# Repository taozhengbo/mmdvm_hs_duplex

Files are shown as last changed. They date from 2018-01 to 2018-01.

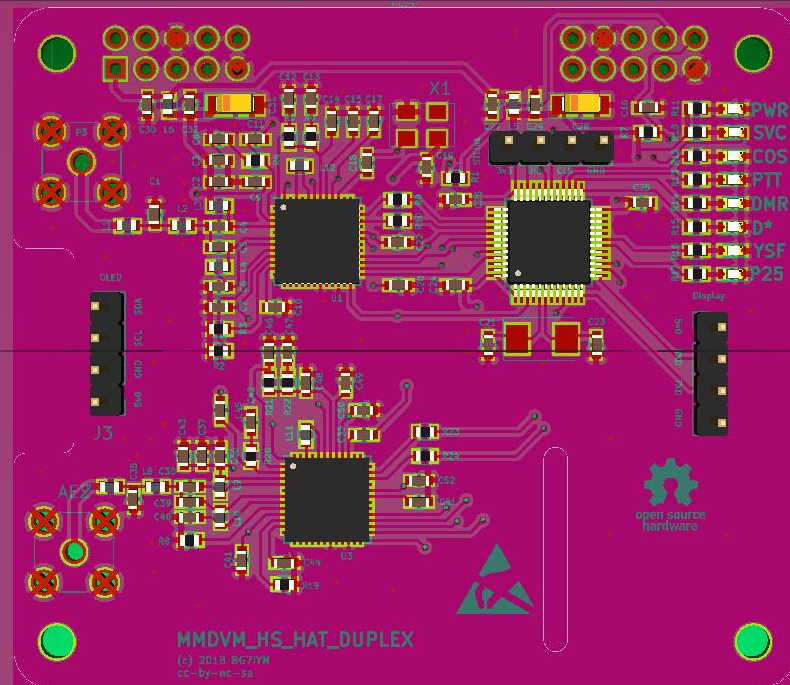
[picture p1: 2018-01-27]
mmdvm_hs-hat-duplex.png

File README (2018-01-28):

# MMDVM_HS_Hat_Duplex
MMDVM_HS Hat Duplex Ver for the Raspberry Pi 

This project provides a Raspberry Pi Hat for the [MMDVM_HS Hotspot](https://github.com/juribeparada/MMDVM_HS). It was designed for the Raspberry Pi any Version, but should work on any other Pi with the Hat interface. 

First revisions of the board have been built successfully!

The PCB is designed in KiCad and the necessary libraries are included. The supplied Gerber files can be used to order PCBs, for example at Elecrow or DirtyPCBs. 

### Revision 1.0 2018-1.25 Tested OK

Either the ADF7021 or the ADF7021-N can be used. Define the proper version in the firmware!

## Firmware Installation
For specific details about the firmware installation, check [these](https://github.com/juribeparada/MMDVM_HS#build-de-firmware-and-upload-to-zumspot-rpi) instructions.  

Enable the following settings in Config.h:

    #define MMDVM_HS_HAT_REV12
    #define ENABLE_ADF7021
    #define ADF7021_14_7456
    #define STM32_USART1_HOST
    #define ENABLE_SCAN_MODE
    #define DUPLEX
it work both DUPLEX or no DUPLEX mode,when in DUPLEX Mode Main RF is TX,Second RF is RX    
Build the firmware:

    make

And finally upload the firmware to the MMDVM_HS_Hat:

    sudo make mmdvm_hs_hat

## License
This project is released under the Creative Commons Attribution-NonCommercial-ShareAlike 3.0 (CC-BY-NC-SA 3.0, https://creativecommons.org/licenses/by-nc-sa/3.0/) license. You may edit and share it as you like, as long as credit is given and the license is not changed. You can build as many boards for you and your friends as you like and you can even sell it to them to cover your costs, **however it is strictly forbidden to turn this into a commercial product! You are not allowed to build and sell these boards for profit!**

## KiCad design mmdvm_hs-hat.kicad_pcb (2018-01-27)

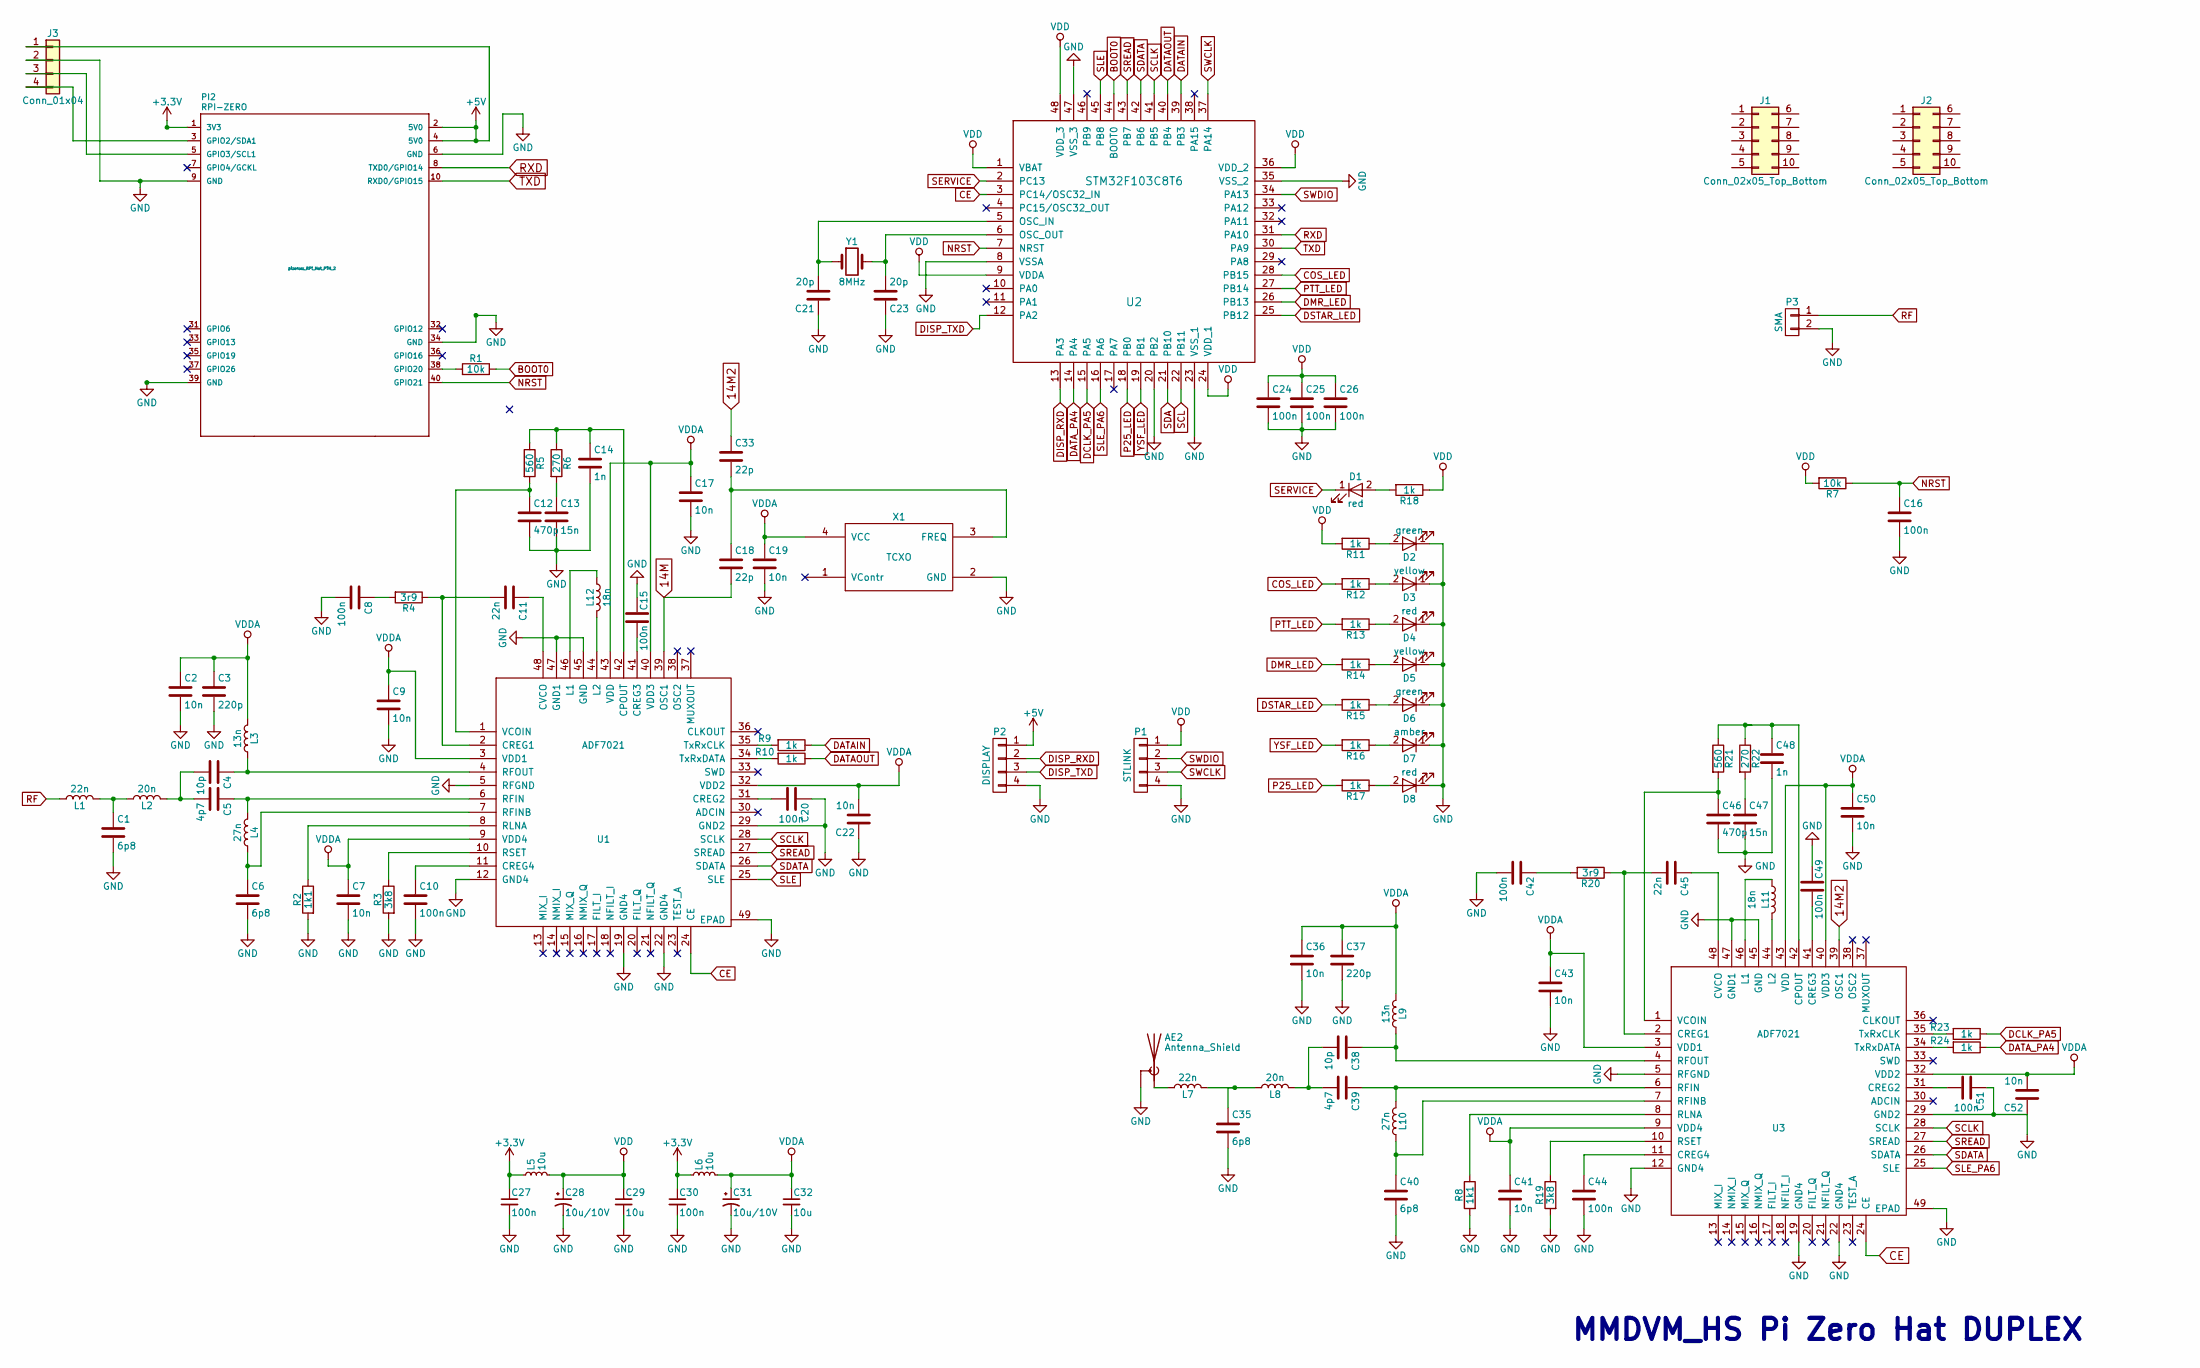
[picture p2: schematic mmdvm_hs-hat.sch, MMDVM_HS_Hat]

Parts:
AE2: Antenna_Shield; SMA_THT_Jack_Straight
C1, C6, C35, C40: 6p8; C_0603; MPN GJM1555C1H6R8BB01D
C2, C7, C9, C17, C19, C22, C36, C41, C43, C50, C52: 10n; C_0603; MPN GRM155R71H103KA88D
C3, C37: 220p; C_0603; MPN GRM1555C1H221JA01D
C4, C38: 10p; C_0603; MPN GRM0225C1C100JA03L
C5, C39: 4p7; C_0603; MPN GRM1555C1H4R7CA01D
C8, C10, C15, C16, C20, C24, C25, C26, C42, C44, C49, C51: 100n; C_0603; MPN GRM022R60J104KE15L
C11, C45: 22n; C_0603; MPN GCM155R71E223KA55D
C12, C46: 470p; C_0603; MPN GRM155R71H471KA01D
C13, C47: 15n; C_0603; MPN GRM155R71C153KA01D
C14, C48: 1n; C_0603; MPN GRM155R60J105KE19D
C18, C33: 22p; C_0603; MPN 04025A220GAT2A
C21, C23: 20p; C_0603; MPN GJM1555C1H200FB01D
C27, C30: 100n; C_0603
C28, C31: 10u/10V; CP_Tantalum_Case-A_EIA-3216-18_Reflow
C29, C32: 10u; C_0603
D1, D4, D8: red; LED_0603; MPN SML-P12U2TT86R
D2, D6: green; LED_0603; MPN SML-P13PTT86R
D3, D5: yellow; LED_0603; MPN SML-P12WTT86R
D7: amber; LED_0603; MPN SML-P12DTT86R
J1, J2: Conn_02x05_Top_Bottom; Pin_Header_Straight_2x05_Pitch2.54mm_SMD
J3: Conn_01x04; Pin_Header_Straight_1x04_Pitch2.54mm
L1, L7: 22n; L_0603; MPN 0402AF-220XJLU
L2, L8: 20n; L_0603; MPN 36501E20NJTDG
L3, L9: 13n; L_0603; MPN 0402CS-13NXJLU
L4, L10: 27n; L_0603; MPN 0402CS-27NXJLU
L5, L6: 10u; L_0603
L11, L12: 18n; L_0603; MPN 0402CS-13NXJLU
P1: STLINK; Pin_Header_Straight_1x04_Pitch2.54mm; MPN 826629-4
P2: DISPLAY; Pin_Header_Straight_1x04_Pitch2.54mm; MPN 826629-4
P3: SMA; SMA_THT_Jack_Straight; MPN 5-1814832-1
PI2: RPI-ZERO; z_RPi_Hat_PTH_2
R1, R7: 10k; R_0603; MPN CRCW040210K0FKED
R2, R8: 1k1; R_0603; MPN RR0510P-112-D
R3, R19: 3k8; R_0603; MPN RR0510P-3831-D
R4, R20: 3r9; R_0603; MPN CRCW04023R90FKED
R5, R21: 560; R_0603; MPN ERA-2AEB561X
R6, R22: 270; R_0603; MPN ERA-2AEB271X
R9, R10, R11, R12, R13, R14, R15, R16, R17, R18, R23, R24: 1k; R_0603; MPN ERJ-PA2D1001X
U1: ADF7021; QFN-48-1EP_7x7mm_Pitch0.5mm; MPN ADF7021BCPZ
U2: STM32F103C8T6; LQFP-48_7x7mm_Pitch0.5mm; MPN STM32F103C8T6
U3: ADF7021; _ADF7021_QFN-48-1EP_7x7mm_Pitch0.5mm
X1: TCXO; Oscillator_SMD_TXC_7C-4pin_5.0x3.2mm; MPN ECS-TXO-3225-147.4-TR
Y1: 8MHz; Crystal_SMD_Abracon_ABM3-2pin_5.0x3.2mm; MPN ABM3-8.000MHz-D2Y-T

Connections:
14M: C18.2, U1.39 (OSC1)
14M2: C33.1, U3.39 (OSC1)
+3V3: C27.1, C30.1, L5.1, L6.1, PI2.1 (3V3)
+5V: J3.1, P2.1, PI2.2 (5V0), PI2.4 (5V0)
BOOT0: R1.1, U2.44 (BOOT0)
CE: U1.24 (CE), U2.3 (PC14/OSC32_IN), U3.24 (CE)
COS_LED: R12.2, U2.28 (PB15)
DATAIN: R9.1, U2.39 (PB3)
DATAOUT: R10.1, U2.40 (PB4)
DATA_PA4: R24.1, U2.14 (PA4)
DCLK_PA5: R23.1, U2.15 (PA5)
DISP_RXD: P2.2, U2.13 (PA3)
DISP_TXD: P2.3, U2.12 (PA2)
DMR_LED: R14.2, U2.26 (PB13)
DSTAR_LED: R15.2, U2.25 (PB12)
GND: AE2.2 (Shield), C1.2, C2.2, C3.2, C6.2, C7.2, C8.2, C9.2, C10.2, C12.2, C13.2, C14.2, C15.1, C16.2, C17.2, C19.2, C20.1, C21.1, C22.1, C23.1, C24.2, C25.2, C26.2, C27.2, C28.2, C29.2, C30.2, C31.2, C32.2, C35.2, C36.2, C37.2, C40.2, C41.2, C42.2, C43.2, C44.2, C46.2, C47.2, C48.2, C49.1, C50.2, C51.1, C52.1, D2.1 (K), D3.1 (K), D4.1 (K), D5.1 (K), D6.1 (K), D7.1 (K), D8.1 (K), J3.2, P1.4, P2.4, P3.2, PI2.6 (GND), PI2.9 (GND), PI2.34 (GND), PI2.39 (GND), R2.2, R3.2, R8.2, R19.2, U1.5 (RFGND), U1.12 (GND4), U1.19 (GND4), U1.22 (GND4), U1.29 (GND2), U1.45 (GND), U1.47 (GND1), U1.49 (EPAD), U2.8 (VSSA), U2.20 (PB2), U2.23 (VSS_1), U2.35 (VSS_2), U2.47 (VSS_3), U3.5 (RFGND), U3.12 (GND4), U3.19 (GND4), U3.22 (GND4), U3.29 (GND2), U3.45 (GND), U3.47 (GND1), U3.49 (EPAD), X1.2 (GND)
NRST: C16.1, PI2.40 (GPIO21), R7.1, U2.7 (NRST)
unnamed: AE2.1 (A), L7.1
unnamed: C1.1, L1.2, L2.1
unnamed: C4.1, L3.1, U1.4 (RFOUT)
unnamed: C4.2, C5.2, L2.2
unnamed: C5.1, L4.2, U1.6 (RFIN)
unnamed: C6.1, L4.1, U1.7 (RFINB)
unnamed: C8.1, R4.2
unnamed: C10.1, U1.11 (CREG4)
unnamed: C11.1, U1.48 (CVCO)
unnamed: C11.2, R4.1, U1.2 (CREG1)
unnamed: C12.1, R5.2, U1.1 (VCOIN)
unnamed: C13.1, R6.2
unnamed: C14.1, R5.1, R6.1, U1.42 (CPOUT)
unnamed: C15.2, U1.41 (CREG3)
unnamed: C18.1, C33.2, X1.3 (FREQ)
unnamed: C20.2, U1.31 (CREG2)
unnamed: C21.2, U2.5 (OSC_IN), Y1.1
unnamed: C23.2, U2.6 (OSC_OUT), Y1.2
unnamed: C35.1, L7.2, L8.1
unnamed: C38.1, L9.1, U3.4 (RFOUT)
unnamed: C38.2, C39.2, L8.2
unnamed: C39.1, L10.2, U3.6 (RFIN)
unnamed: C40.1, L10.1, U3.7 (RFINB)
unnamed: C42.1, R20.2
unnamed: C44.1, U3.11 (CREG4)
unnamed: C45.1, U3.48 (CVCO)
unnamed: C45.2, R20.1, U3.2 (CREG1)
unnamed: C46.1, R21.2, U3.1 (VCOIN)
unnamed: C47.1, R22.2
unnamed: C48.1, R21.1, R22.1, U3.42 (CPOUT)
unnamed: C49.2, U3.41 (CREG3)
unnamed: C51.2, U3.31 (CREG2)
unnamed: D1.2 (A), R18.2
unnamed: D2.2 (A), R11.1
unnamed: D3.2 (A), R12.1
unnamed: D4.2 (A), R13.1
unnamed: D5.2 (A), R14.1
unnamed: D6.2 (A), R15.1
unnamed: D7.2 (A), R16.1
unnamed: D8.2 (A), R17.1
unnamed: J3.3, PI2.5 (GPIO3/SCL1)
unnamed: J3.4, PI2.3 (GPIO2/SDA1)
unnamed: L11.1, U3.46 (L1)
unnamed: L11.2, U3.44 (L2)
unnamed: L12.1, U1.46 (L1)
unnamed: L12.2, U1.44 (L2)
unnamed: PI2.38 (GPIO20), R1.2
unnamed: R2.1, U1.8 (RLNA)
unnamed: R3.1, U1.10 (RSET)
unnamed: R8.1, U3.8 (RLNA)
unnamed: R9.2, U1.35 (TxRxCLK)
unnamed: R10.2, U1.34 (TxRxDATA)
unnamed: R19.1, U3.10 (RSET)
unnamed: R23.2, U3.35 (TxRxCLK)
unnamed: R24.2, U3.34 (TxRxDATA)
P25_LED: R17.2, U2.18 (PB0)
PTT_LED: R13.2, U2.27 (PB14)
RF: L1.1, P3.1
RXD: PI2.8 (TXD0/GPIO14), U2.31 (PA10)
SCL: U2.22 (PB11)
SCLK: U1.28 (SCLK), U2.41 (PB5), U3.28 (SCLK)
SDA: U2.21 (PB10)
SDATA: U1.26 (SDATA), U2.42 (PB6), U3.26 (SDATA)
SERVICE: D1.1 (K), U2.2 (PC13)
SLE: U1.25 (SLE), U2.45 (PB8)
SLE_PA6: U2.16 (PA6), U3.25 (SLE)
SREAD: U1.27 (SREAD), U2.43 (PB7), U3.27 (SREAD)
SWCLK: P1.3, U2.37 (PA14)
SWDIO: P1.2, U2.34 (PA13)
TXD: PI2.10 (RXD0/GPIO15), U2.30 (PA9)
VDD: C24.1, C25.1, C26.1, C28.1, C29.1, L5.2, P1.1, R7.2, R11.2, R18.1, U2.1 (VBAT), U2.9 (VDDA), U2.24 (VDD_1), U2.36 (VDD_2), U2.48 (VDD_3)
VDDA: C2.1, C3.1, C7.1, C9.1, C17.1, C19.1, C22.2, C31.1, C32.1, C36.1, C37.1, C41.1, C43.1, C50.1, C52.2, L3.2, L6.2, L9.2, U1.3 (VDD1), U1.9 (VDD4), U1.32 (VDD2), U1.40 (VDD3), U1.43 (VDD), U3.3 (VDD1), U3.9 (VDD4), U3.32 (VDD2), U3.40 (VDD3), U3.43 (VDD), X1.4 (VCC)
YSF_LED: R16.2, U2.19 (PB1)

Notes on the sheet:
MMDVM_HS Pi Zero Hat DUPLEX

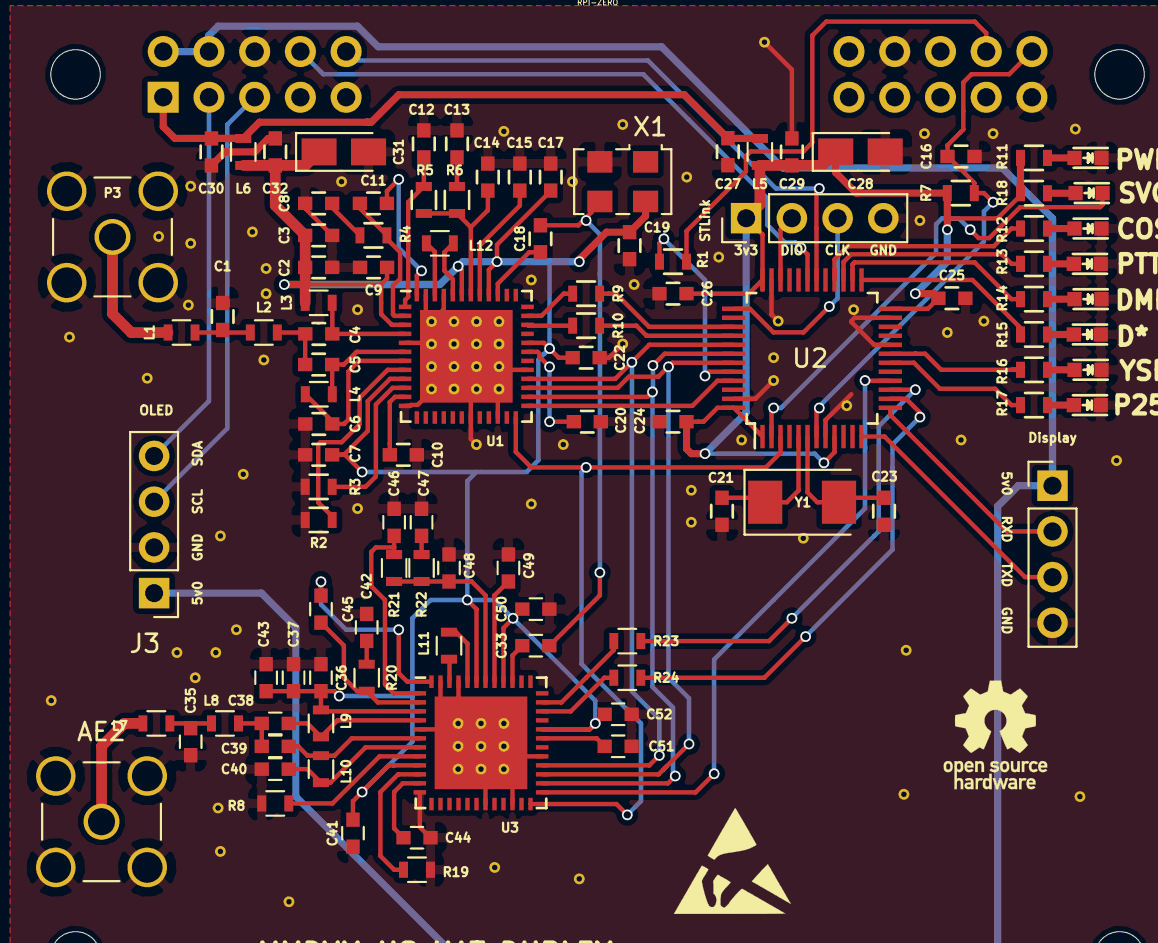
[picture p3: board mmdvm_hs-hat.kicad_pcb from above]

Board: 2 copper layers, 106 parts (0 on the bottom side), 88 nets.

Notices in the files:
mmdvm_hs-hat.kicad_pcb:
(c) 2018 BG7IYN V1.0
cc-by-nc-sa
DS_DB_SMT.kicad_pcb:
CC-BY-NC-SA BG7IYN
